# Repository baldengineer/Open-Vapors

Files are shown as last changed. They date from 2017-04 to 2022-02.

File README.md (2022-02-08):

# Open Vapors - Open Source Reflow Oven Controller

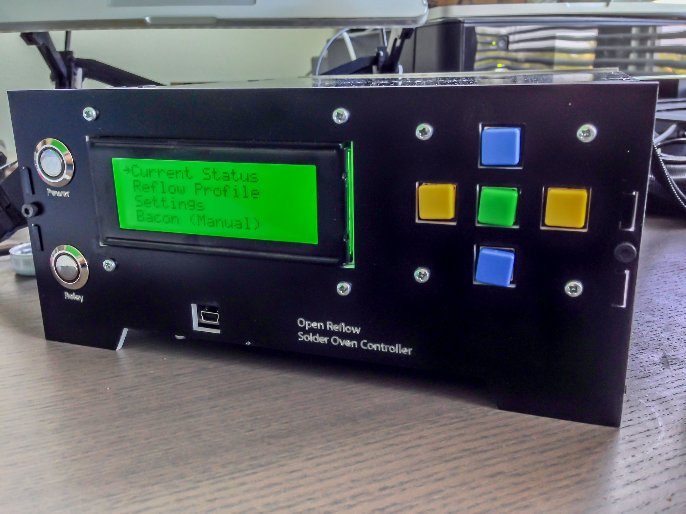
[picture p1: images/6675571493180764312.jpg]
bald engineer's open vapors reflow controller box


Additional Information on [baldengineer.com]( https://www.baldengineer.com/?s=open+vapors).

Key hardware pieces you'll need:
+ Toaster Oven with "Always On"
+ Custom controller board (or maybe an Arduino)
+ SSR (Recommend Crydom D2425)
+ 4-Line RGB LCD Display
+ 5 Button Keypad
+ 1 Push Button
+ Piezo Buzzer 

## /code
Contains all of the code for the menu display and reflow controller.

## /KiCad
The revision 2 board is a significant redesign from the first board. It integrates the shift register for the LCD and implements voltage rails to massively reduce internal wiring. Headers were also position to logical places on the PCB.

Buzzer is optional, but now implemented. USB connection through a 0.1" (2.54mm) header to a USB-port breakout. It is only intended for serial operation.

Recommend using ISP for programming. 

Also added port for AT-09 BLE module. (Not yet implemented)

## /enclosure
Laser cut enclosure. The top, bottom, and sides used 3mm black acrylic. The front and back panels are Black on White acrylic.

Originally designed in Autocad Inventor, student edition. Then exported to Adobe Illustrator (CS6 I think) files.

The bottom needs to be redesigned to get more support. ~~The SSR warps it over time.~~ After almost 5 years, it hasn't sagged anymore. I would still recommend a support around the SSR though.

## /original electronics - EAGLE
Rev 1 was created using an EAGLE. It worked okay, but relied on a "LCD Backpack" and was not an optimized design. (LEDs in the wrong place.) 

That said, it worked great for years.

The original keypad is in use still. Even though the debounce caps were totally wrong.

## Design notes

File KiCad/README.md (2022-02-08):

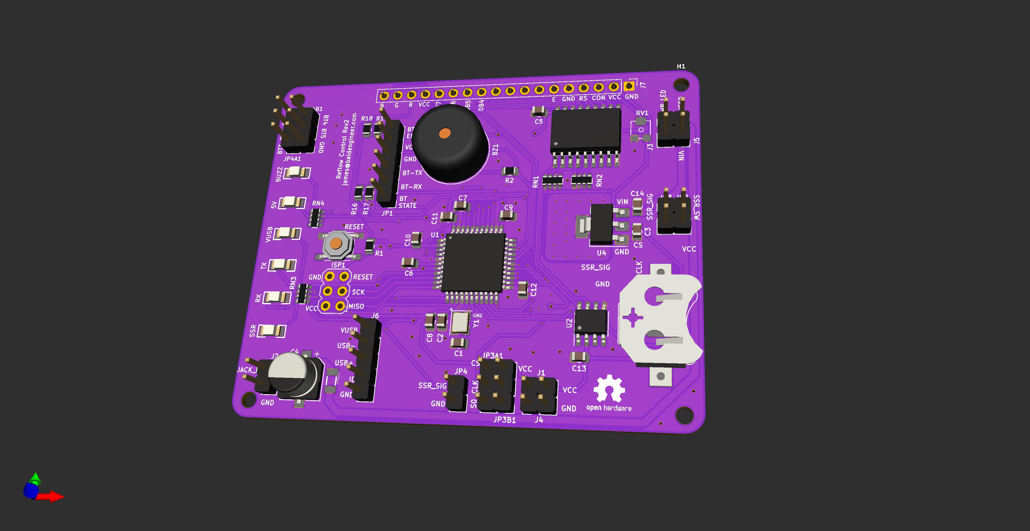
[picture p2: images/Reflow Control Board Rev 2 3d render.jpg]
board render


## KiCad Files
The first design used EAGLE 6. I converted the EAGLE files into KiCad 5. This reduced the time to re-capture the schematic but it also caused a mess with the libraries and silk screens.

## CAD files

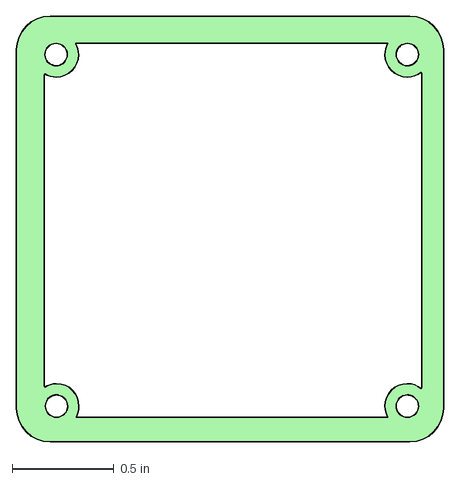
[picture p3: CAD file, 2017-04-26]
enclosure/spaces-3d-printed/Keypad Board/keypad_spacer.dxf
2.10 x 2.10 in

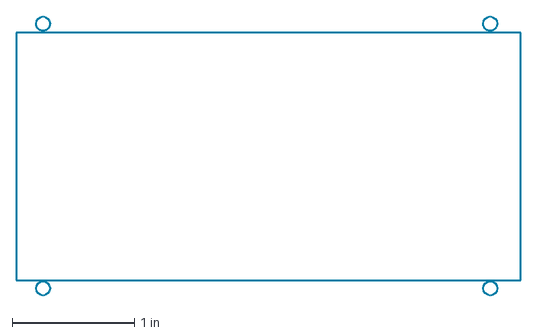
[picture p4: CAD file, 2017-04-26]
enclosure/spaces-3d-printed/lcd/lcd spacer for dxf.dxf
4.14 x 2.29 in

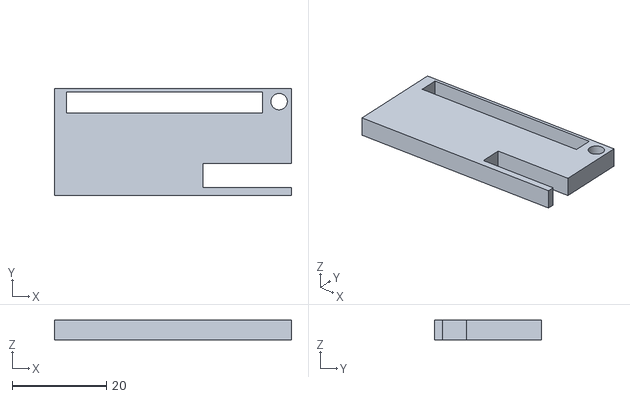
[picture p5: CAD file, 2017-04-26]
enclosure/spaces-3d-printed/spi backpack/spi backpack v1.stl
50.4 x 22.7 x 4.25

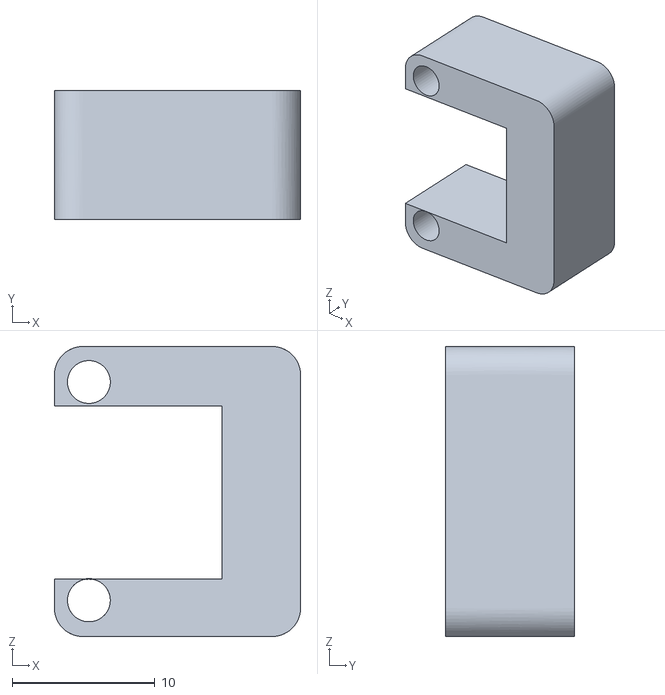
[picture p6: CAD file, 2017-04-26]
enclosure/spaces-3d-printed/thermo-board/thermo-v1.stl
17.2 x 9.00 x 20.3

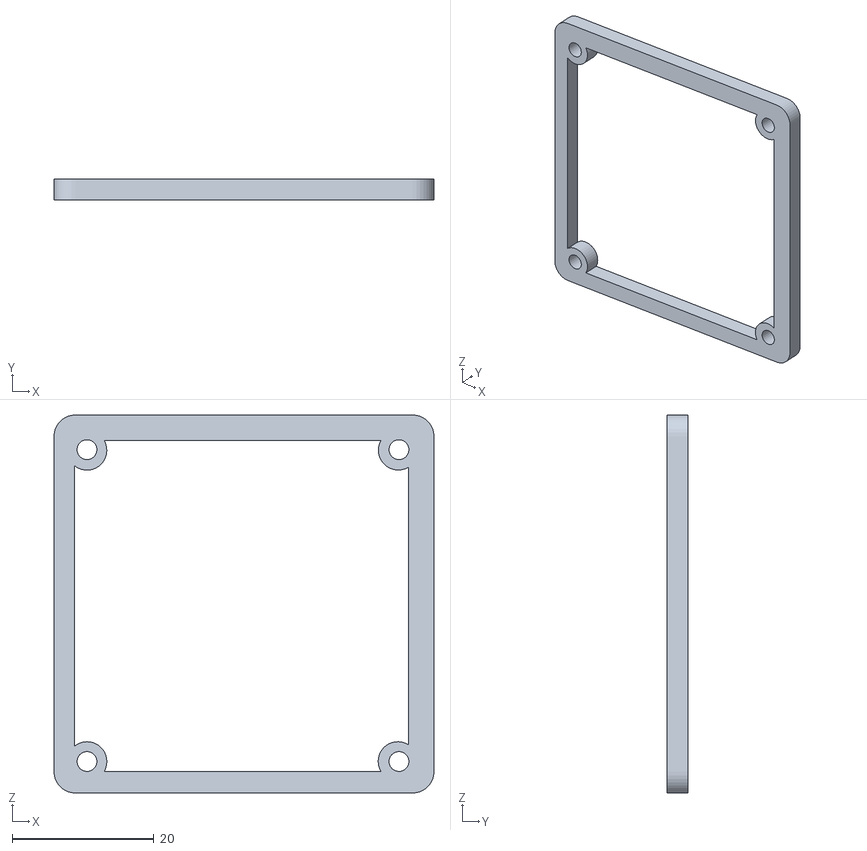
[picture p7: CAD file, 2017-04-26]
enclosure/spaces-3d-printed/Keypad Board/keyboard_space_cad.stl
53.6 x 3.00 x 53.3

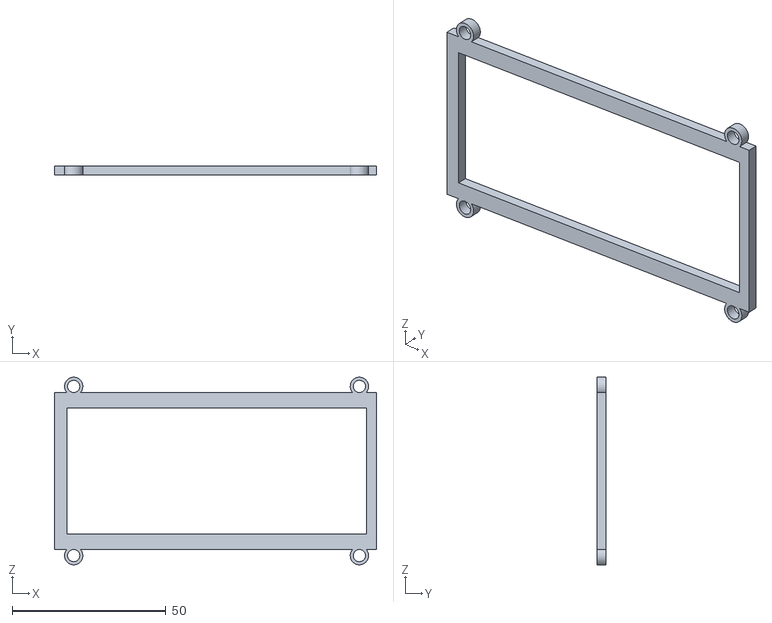
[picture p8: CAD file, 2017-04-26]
enclosure/spaces-3d-printed/lcd/lcd-v1.stl
104.9 x 3.00 x 61.1

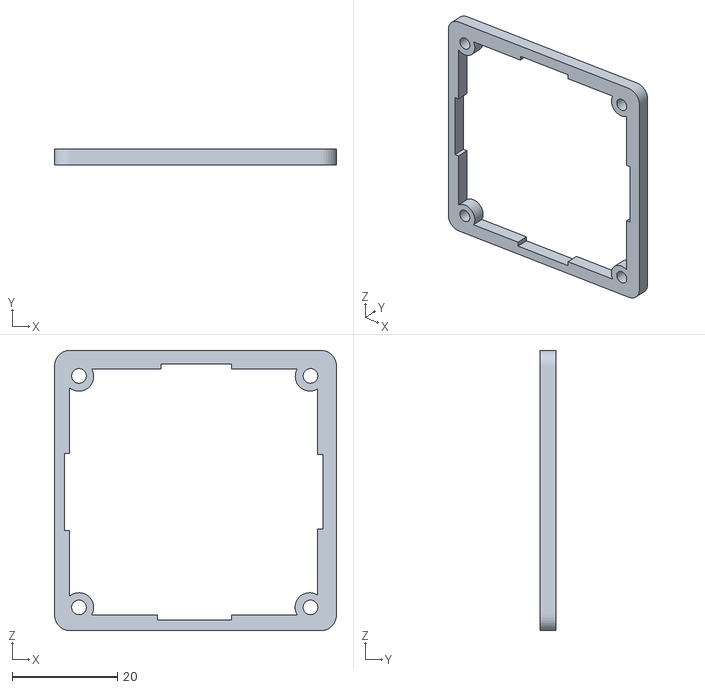
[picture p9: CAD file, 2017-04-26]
enclosure/spaces-3d-printed/Keypad Board/keyboard_space_cad2.stl
53.6 x 3.00 x 53.3

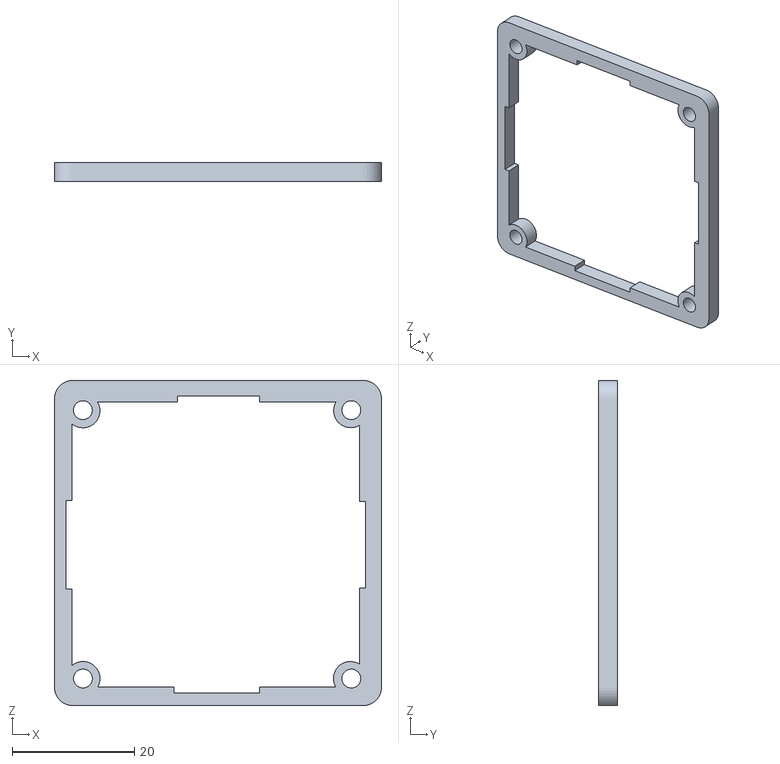
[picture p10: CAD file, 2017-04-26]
enclosure/spaces-3d-printed/Keypad Board/keyboard_space_cad3.stl
53.6 x 3.10 x 53.3

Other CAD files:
enclosure/box-autocad-inventor/Bottom Panel.ipt
enclosure/box-autocad-inventor/Box Back.ipt
enclosure/box-autocad-inventor/Box Bottom.ipt
enclosure/box-autocad-inventor/Box Front.ipt
enclosure/box-autocad-inventor/Box Side Panel.ipt
enclosure/box-autocad-inventor/Box Top.ipt
enclosure/box-autocad-inventor/Front Panel.ipt
enclosure/box-autocad-inventor/Reflow Oven Assembly.iam
enclosure/box-autocad-inventor/open reflow box.ipt
enclosure/spaces-3d-printed/Controller Board/cntrl-space-partA.ipt
enclosure/spaces-3d-printed/Keypad Board/keyboard_space_cad.ipt
enclosure/spaces-3d-printed/lcd/lcd-spacer-model.ipt
enclosure/spaces-3d-printed/spi backpack/spi backpack model.ipt
enclosure/spaces-3d-printed/thermo-board/thermo-model.ipt

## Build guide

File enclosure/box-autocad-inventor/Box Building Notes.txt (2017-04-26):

NEMA 5 model from GrabCad:  http://grabcad.com/library/industrial-grade-nema-5-15-duplex-receptacle

Panel Mount OUtlet:  http://www.mouser.com/catalog/specsheets/710w0003.pdf
http://www.mouser.com/ProductDetail/Qualtek/710W-00-03/?qs=sGAEpiMZZMv1TUPJeFpwbm7YVXuSB9VCPmF%252bPdpxbIk%3d

Panel Mount Inlet:  http://www.mouser.com/ds/1/337/744w0004-10363.pdf
http://www.mouser.com/ProductDetail/Qualtek/744W-00-04/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

Understanding engineering drawings: http://www.wisc-online.com/Objects/ViewObject.aspx?ID=ENG18704

Fuse Holder:  http://www1.cooperbussmann.com/pdf/6a0cf653-3423-48a4-b0d8-5b3b433e4858.pdf
http://www.mouser.com/Search/ProductDetail.aspx?qs=jGANiKWBgci5Io4vQID5Tg%3d%3d

Sharp Triac / SSR S216S02  http://sharp-world.com/products/device/lineup/data/pdf/datasheet/s116s02_e.pdf
beta layout reflow controller 120v

Dc Panel Mount:
http://www.mouser.com/catalog/specsheets/KC-301074.pdf
http://www.mouser.com/ProductDetail/Kobiconn/163-R123B-E/?qs=sGAEpiMZZMu2f9RNbWupYr29NQTi4RUSfGRFGZxAbjk%3d

Terminal Blocks
http://www.mouser.com/Search/ProductDetail.aspx?qs=nJOu%252bf4e%252bhtchGRXi4U3dQ%3d%3d

Check out skyrocket:  http://skyrockettheband.com/video_index.html

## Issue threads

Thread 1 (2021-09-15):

rev2 pcb for controller has battery mistake

baldengineer, 2021-09-15:
The RTC's battery connector footprint does not connect to GND. There is a mistake in the KiCad schematic that did not connect the nets.

It is necessary to scrape the solder mask and bodge a connection to the nearby GND.

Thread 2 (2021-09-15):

Power LED connector is not connected

baldengineer, 2021-09-15:
On the pin headers for the front panel buttons, there is a pin for "power LED." the Pin on the  2x1 (or 2x2, depending on how you look at it) isn't connected to anything.

Need to connect front panel's switches power LED to a 5V node elsewhere.

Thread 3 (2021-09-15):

PID is wonky

baldengineer, 2021-09-15:
In reviewing the latest reflow state machine and PID code, it is clear the intern took the "hardcode the profile" shortcut.

While changing the profile is possible, the state machine has several shortcuts that should have been figured out with proper tuning.

Will schedule a sit-down with the intern.

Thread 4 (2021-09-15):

Add a fan

baldengineer, 2021-09-15:
The PID would be significantly more effective if fan control was possible.

Is there a way to add a fan to the oven that won't melt?

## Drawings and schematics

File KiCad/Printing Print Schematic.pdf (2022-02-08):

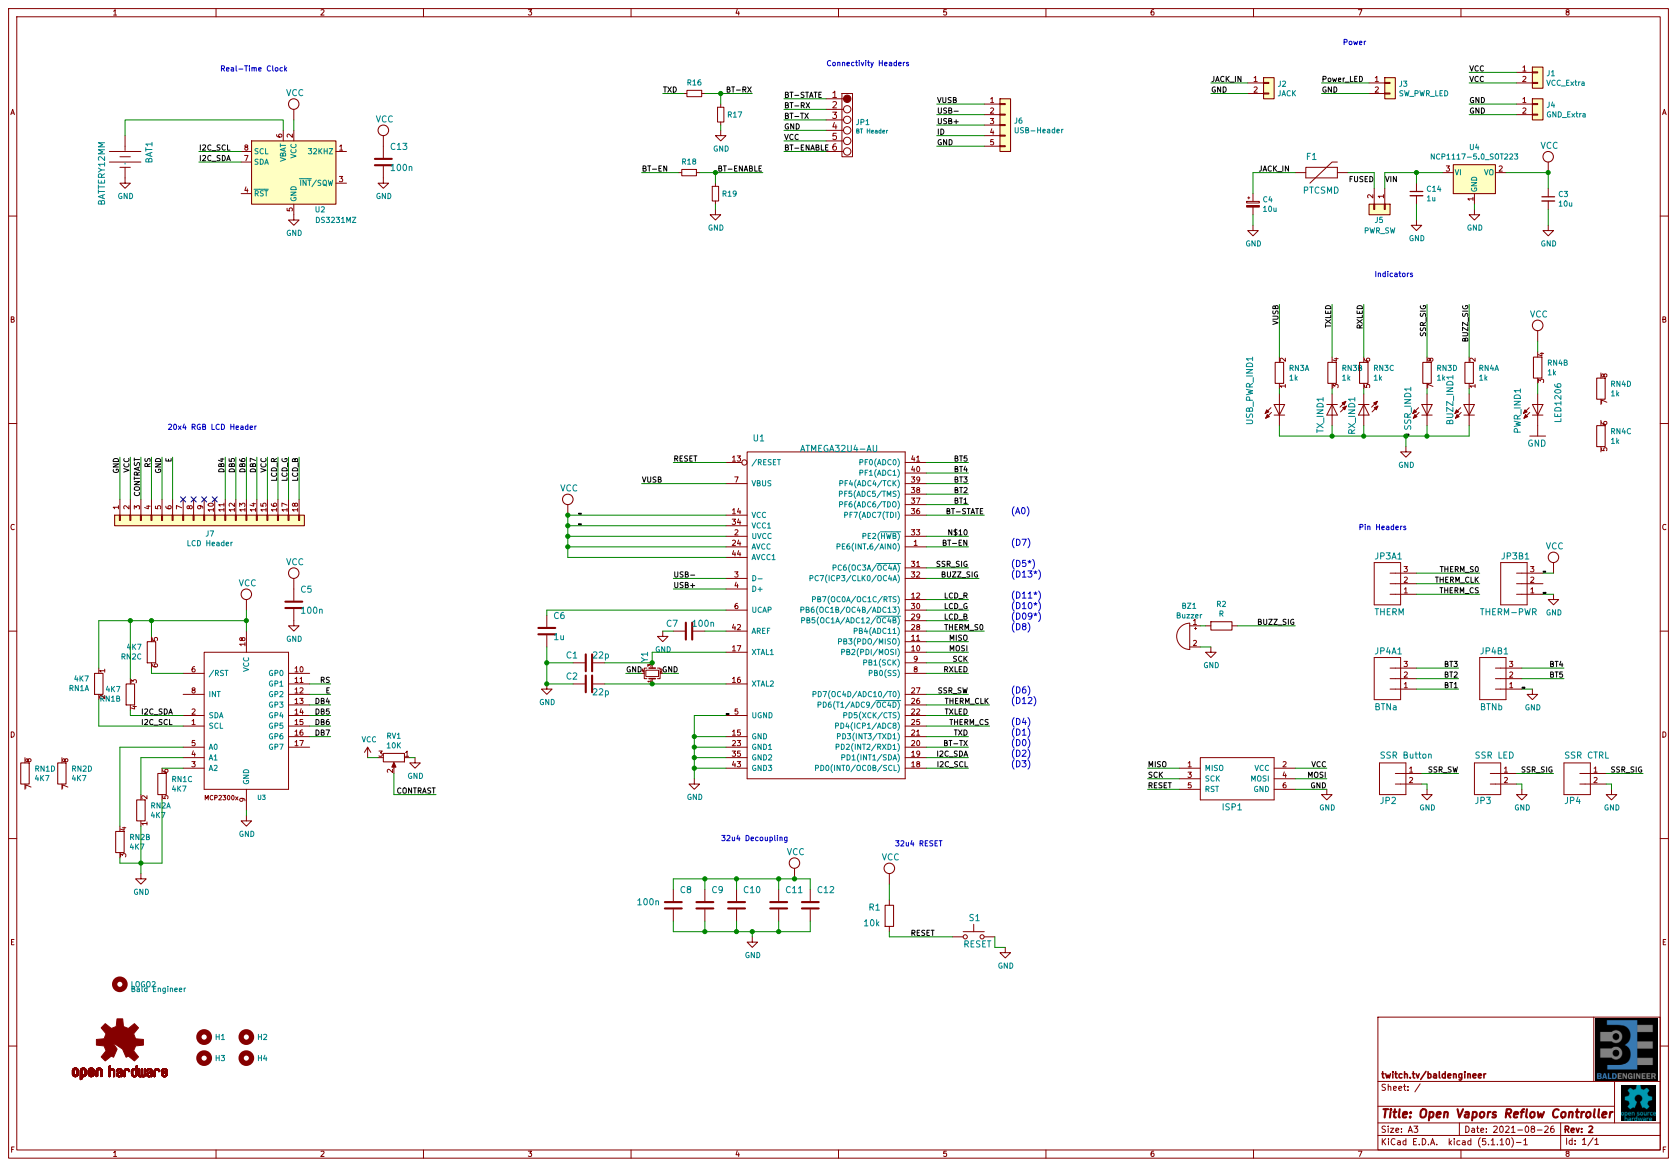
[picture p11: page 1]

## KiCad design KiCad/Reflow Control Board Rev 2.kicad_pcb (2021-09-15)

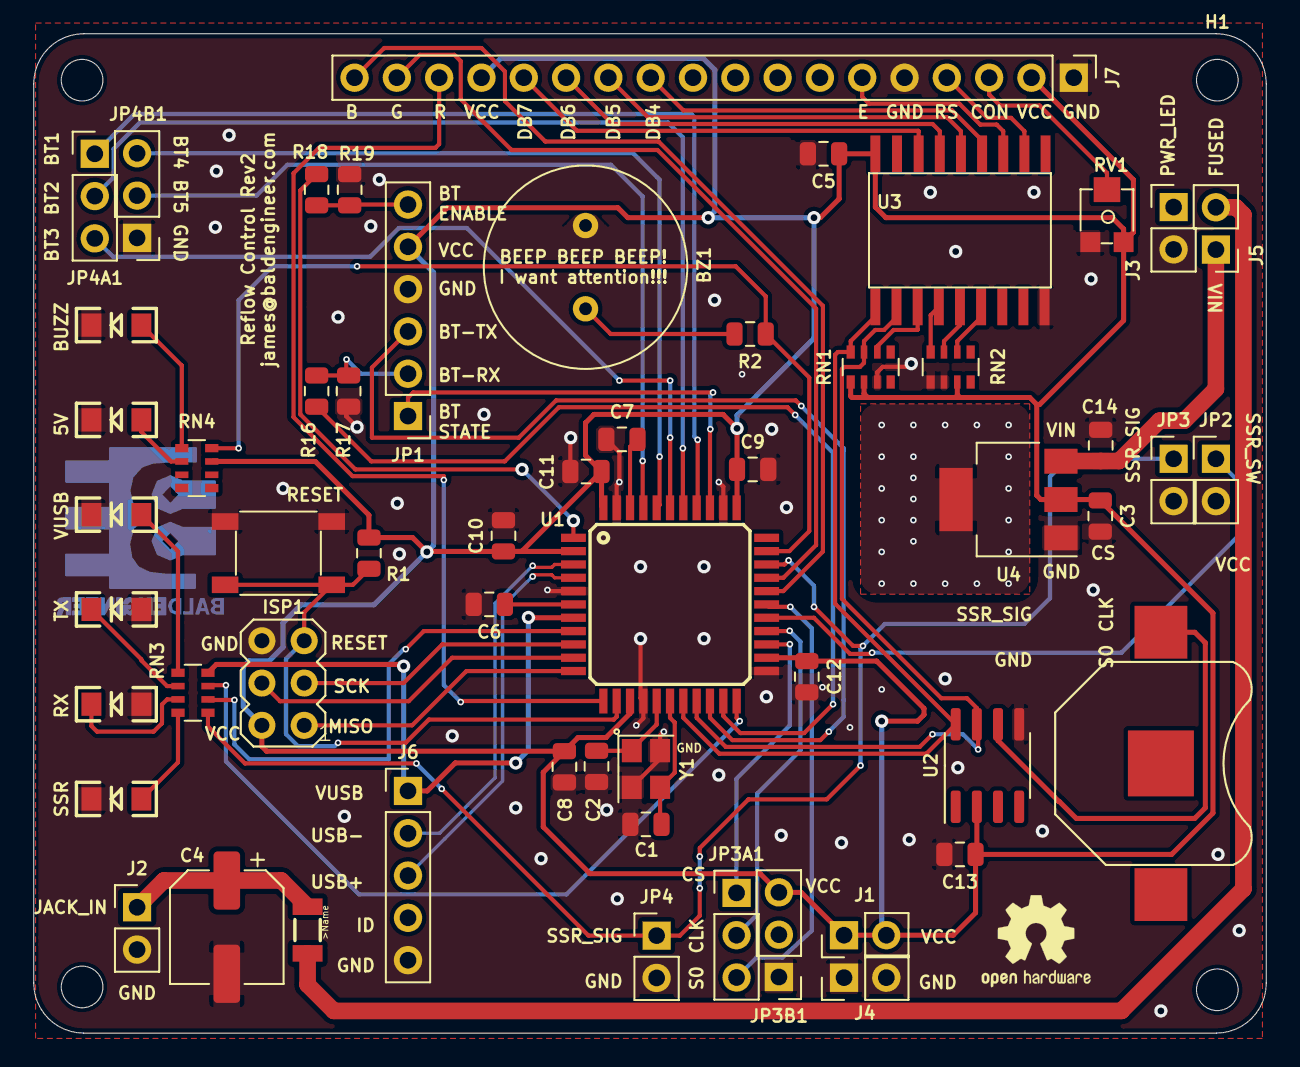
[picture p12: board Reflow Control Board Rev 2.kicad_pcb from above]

Board: 2 copper layers, 74.0 x 60.0 mm, 62 parts (0 on the bottom side), 59 nets.

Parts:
BAT1: BATTERY12MM; BATTCON_12MM
BUZZ_IND1: LED1206; LED-1206
BZ1: Buzzer; 12mm_Piezo_Buzzer
C1, C2: 22p; C_0805_2012Metric
C3: 10u; C_0805_2012Metric
C4: 10u; CP_Elec_6.3x5.9
C5, C7, C8, C9, C10, C11, C12, C13: 100n; C_0805_2012Metric
C6, C14: 1u; C_0805_2012Metric
F1: PTCSMD; PTC-1206
H1, H2, H3, H4: MountingHole; MountingHole_2.5mm
ISP1: AVRISP-6; AVRISP
J1: VCC_Extra; PinHeader_1x02_P2.54mm_Vertical
J2: JACK; PinHeader_1x02_P2.54mm_Vertical
J3: SW_PWR_LED; PinHeader_1x02_P2.54mm_Vertical
J4: GND_Extra; PinHeader_1x02_P2.54mm_Vertical
J5: PWR_SW; PinHeader_1x02_P2.54mm_Vertical
J6: USB-Header; PinHeader_1x05_P2.54mm_Vertical
J7: LCD Header; PinHeader_1x18_P2.54mm_Vertical
JP1: BT Header; PinHeader_1x06_P2.54mm_Vertical
JP2: SSR Button; PinHeader_1x02_P2.54mm_Vertical
JP3: SSR LED; PinHeader_1x02_P2.54mm_Vertical
JP3A1: THERM; PinHeader_1x03_P2.54mm_Vertical
JP3B1: THERM-PWR; PinHeader_1x03_P2.54mm_Vertical
JP4: SSR CTRL; PinHeader_1x02_P2.54mm_Vertical
JP4A1: BTNa; PinHeader_1x03_P2.54mm_Vertical
JP4B1: BTNb; PinHeader_1x03_P2.54mm_Vertical
LOGO1: OSHW-LOGOM; OSHW-Logo2_7.3x6mm_SilkScreen
PWR_IND1: LED1206; LED-1206
R1: 10k; R_0805_2012Metric
R2: R; R_0805_2012Metric
R16, R17, R18, R19: R_Small; R_0805_2012Metric
RN1, RN2: 4K7; R_Array_Convex_4x0603
RN3, RN4: 1k; R_Array_Convex_4x0603
RV1: 10K; EVM3Y
RX_IND1: LED1206; LED-1206
S1: RESET; SW_Push_CK_PTS525_SM15
SSR_IND1: LED1206; LED-1206
TX_IND1: LED1206; LED-1206
U1: ATMEGA32U4-AU; TQFP44
U2: DS3231MZ; SOIC-8_3.9x4.9mm_P1.27mm
U3: MCP2300X_SO; SO18W
U4: NCP1117-5.0_SOT223; SOT-223-3_TabPin2
USB_PWR_IND1: LED1206; LED-1206
Y1: CRYSTALHC49US; Crystal_SMD_Abracon_ABM8G-4Pin_3.2x2.5mm
svg2mod: G***; BE20

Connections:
/BT1: JP4A1.1, U1.37
/BT2: JP4A1.2, U1.38
/BT3: JP4A1.3, U1.39
/BT4: JP4B1.3, U1.40
/BT5: JP4B1.2, U1.41
/BT-EN: R18.2, U1.1
/BT-ENABLE: JP1.6, R18.1, R19.1
/BT-RX: JP1.2, R16.1, R17.1
/BT-STATE: JP1.1, U1.36
/BT-TX: JP1.3, U1.20
/BUZZ_SIG: R2.1, RN4.2, U1.32
/CONTRAST: J7.3, RV1.2
/DB4: J7.11, U3.13
/DB5: J7.12, U3.14
/DB6: J7.13, U3.15
/DB7: J7.14, U3.16
/E: J7.6, U3.12
/FUSED: F1.2, J5.2
/I2C_SCL: RN1.2, U1.18, U2.8, U3.1
/I2C_SDA: RN1.4, U1.19, U2.7, U3.2
/JACK_IN: C4.1, F1.1, J2.1
/LCD_B: J7.18, U1.29
/LCD_G: J7.17, U1.30
/LCD_R: J7.16, U1.12
/MISO: ISP1.1, U1.11
/MOSI: ISP1.4, U1.10
/RESET: ISP1.5, R1.2, S1.1, U1.13
/RS: J7.4, U3.11
/RXLED: RN3.6, U1.8
/SCK: ISP1.3, U1.9
/SSR_SIG: JP3.1, JP4.1, RN3.8, U1.31
/SSR_SW: JP2.1, U1.27
/THERM_CLK: JP3A1.2, U1.26
/THERM_CS: JP3A1.1, U1.25
/THERM_S0: JP3A1.3, U1.28
/TXD: R16.2, U1.21
/TXLED: RN3.4, U1.22
/USB+: J6.3, U1.4
/USB-: J6.2, U1.3
/VIN: C14.1, J5.1, U4.3
/VUSB: J6.1, RN3.2, U1.7
GND: BUZZ_IND1.C, BZ1.2, C1.1, C2.1, C3.2, C4.2, C5.2, C6.2, C7.1, C8.2, C9.2, C10.2, C11.2, C12.2, C13.2, C14.2, ISP1.6, J2.2, J3.2, J4.1, J4.2, J6.5, J7.1, J7.5, JP1.4, JP2.2, JP3.2, JP3B1.1, JP4.2, JP4B1.1, PWR_IND1.C, R17.2, R19.2, RN1.5, RN2.1, RN2.3, RV1.1, RX_IND1.A, S1.2, SSR_IND1.C, TX_IND1.A, U1.5, U1.15, U1.23, U1.35, U1.43, U2.5, U3.9, U4.1, USB_PWR_IND1.C, Y1.2, Y1.4
unnamed: BAT1.PWR@2, U2.6
unnamed: BUZZ_IND1.A, RN4.1
unnamed: BZ1.1, R2.2
unnamed: C1.2, U1.17, Y1.3
unnamed: C2.2, U1.16, Y1.1
unnamed: C6.1, U1.6
unnamed: C7.2, U1.42
unnamed: PWR_IND1.A, RN4.3
unnamed: RN1.6, U3.3
unnamed: RN2.2, U3.4
unnamed: RN2.4, U3.5
unnamed: RN2.6, U3.6
unnamed: RN3.1, USB_PWR_IND1.A
unnamed: RN3.3, TX_IND1.C
unnamed: RN3.5, RX_IND1.C
unnamed: RN3.7, SSR_IND1.A
VCC: C3.1, C5.1, C8.1, C9.1, C10.1, C11.1, C12.1, C13.1, ISP1.2, J1.1, J1.2, J7.2, J7.15, JP1.5, JP3B1.3, R1.1, RN1.1, RN1.3, RN2.5, RN4.4, RV1.3, U1.2, U1.14, U1.24, U1.34, U1.44, U2.2, U3.18, U4.2

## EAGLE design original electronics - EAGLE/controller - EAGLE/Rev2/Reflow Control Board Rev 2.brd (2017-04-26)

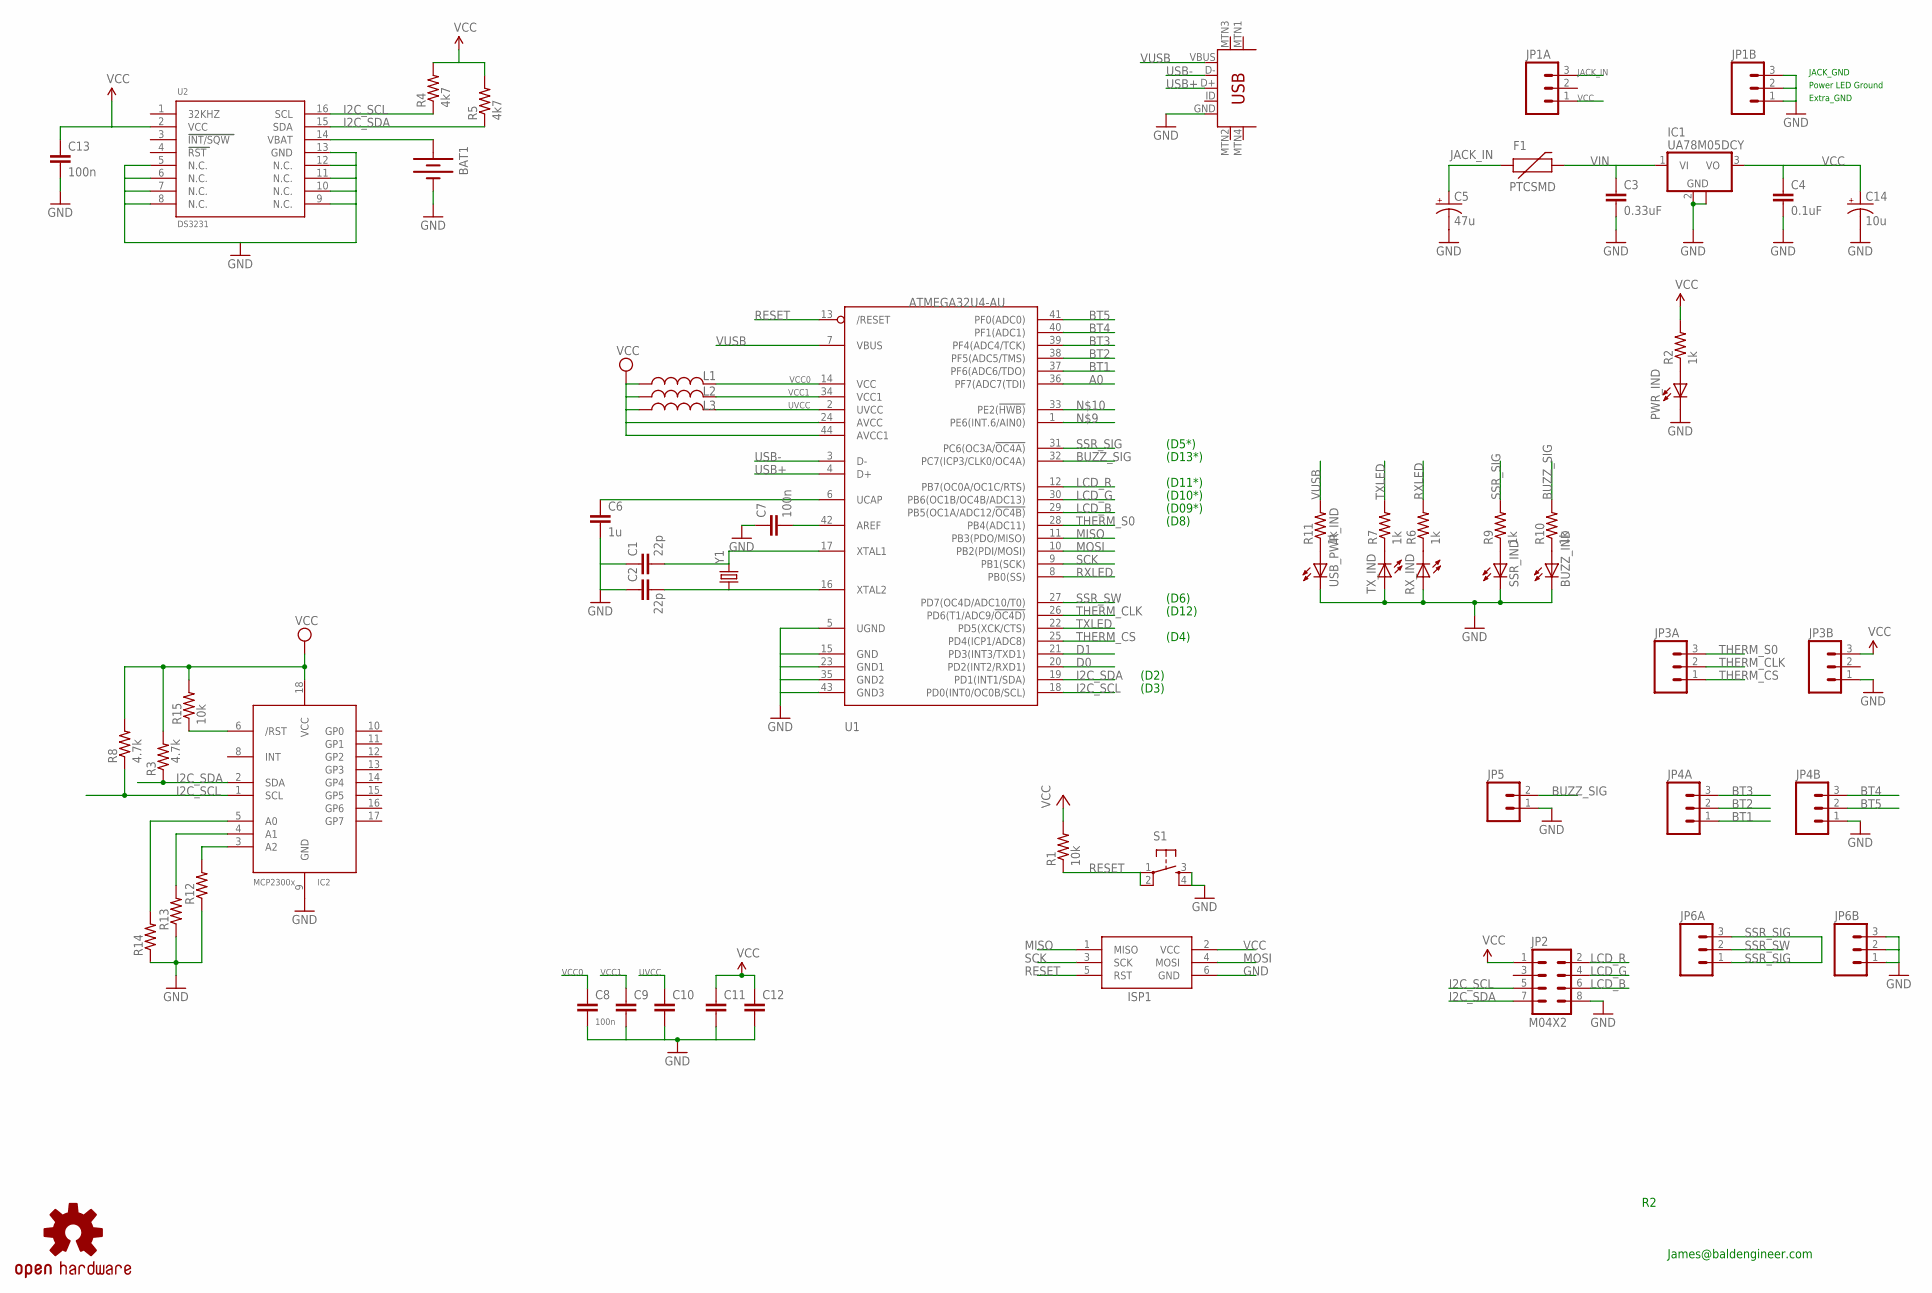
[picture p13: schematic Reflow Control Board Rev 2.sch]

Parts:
BAT1: BATTERY12MM; BATTCON_12MM
BUZZ_IND: LED1206; LED-1206
C1, C2: 22p; 1206
C3: 0.33uF; 1206
C4: 0.1uF; 1206
C5: 47u; D/7343-31R
C6: 1u; 1206
C7, C8, C9, C10, C11, C12, C13: 100n; 1206
C14: 10u; D/7343-31R
F1: PTCSMD; PTC-1206
IC1: UA78M05DCY; SOT223
IC2: MCP2300X/SO; SO18W
ISP1: AVRISP-6; AVRISP
JP1A, JP1B, JP3A, JP3B, JP4A, JP4B, JP6A, JP6B: M03LOCK; 1X03_LOCK
JP2: M04X2; 2X4
JP5: M02LOCK; 1X02_LOCK
L1, L2, L3: INDUCTOR0805; 0805
PWR_IND: LED1206; LED-1206
R1, R15: 10k; 1206
R2, R6, R7, R9, R10, R11: 1k; 1206
R3, R8: 4.7k; 1206
R4, R5: 4k7; 1206
R12, R13, R14: RESISTOR1206; 1206
RX_IND: LED1206; LED-1206
S1: TAC_SWITCHSMD; TACTILE_SWITCH_SMD
SSR_IND: LED1206; LED-1206
TX_IND: LED1206; LED-1206
U1: ATMEGA32U4-AU; TQFP44
U2: DS3231; SO16L
U$3: USB-MINIB-5PIN; USB-MINIB
U$4: OSHW-LOGOS; OSHW-LOGO-S
USB_PWR_IND: LED1206; LED-1206
Y1: CRYSTALHC49US; HC49US

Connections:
A0: U1.36 (PF7(ADC7(TDI))
BT1: JP4A.1, U1.37 (PF6(ADC6/TDO))
BT2: JP4A.2, U1.38 (PF5(ADC5/TMS))
BT3: JP4A.3, U1.39 (PF4(ADC4/TCK))
BT4: JP4B.3, U1.40 (PF1(ADC1))
BT5: JP4B.2, U1.41 (PF0(ADC0))
BUZZ_SIG: JP5.2, R10.2, U1.32 (PC7(ICP3/CLK0/OC4A))
D0: U1.20 (PD2(INT2/RXD1))
D1: U1.21 (PD3(INT3/TXD1))
GND: BAT1.GND (-), BUZZ_IND.C, C1.1, C2.1, C3.2, C4.2, C5.-, C6.2, C7.1, C8.2, C9.2, C10.2, C11.2, C12.2, C13.2, C14.-, IC1.2 (GND), IC1.4 (GND), IC2.9 (GND), ISP1.6 (GND), JP1B.1, JP1B.2, JP1B.3, JP2.8, JP3B.1, JP4B.1, JP5.1, JP6B.1, JP6B.2, JP6B.3, PWR_IND.C, R12.1, R13.1, R14.1, RX_IND.A, S1.3, S1.4, SSR_IND.C, TX_IND.A, U1.5 (UGND), U1.15 (GND), U1.23 (GND1), U1.35 (GND2), U1.43 (GND3), U2.5 (N.C.), U2.6 (N.C.), U2.7 (N.C.), U2.8 (N.C.), U2.9 (N.C.), U2.10 (N.C.), U2.11 (N.C.), U2.12 (N.C.), U2.13 (GND), U$3.GND, USB_PWR_IND.C
I2C_SCL: IC2.1 (SCL), JP2.5, R4.1, R8.1, U1.18 (PD0(INT0/OC0B/SCL)), U2.16 (SCL)
I2C_SDA: IC2.2 (SDA), JP2.7, R3.1, R5.1, U1.19 (PD1(INT1/SDA)), U2.15 (SDA)
JACK_IN: C5.+, F1.1, JP1A.3
LCD_B: JP2.6, U1.29 (PB5(OC1A/ADC12/!OC4B))
LCD_G: JP2.4, U1.30 (PB6(OC1B/OC4B/ADC13))
LCD_R: JP2.2, U1.12 (PB7(OC0A/OC1C/RTS))
MISO: ISP1.1 (MISO), U1.11 (PB3(PDO/MISO))
MOSI: ISP1.4 (MOSI), U1.10 (PB2(PDI/MOSI))
unnamed: C1.2, U1.17 (XTAL1), Y1.2
unnamed: C2.2, U1.16 (XTAL2), Y1.1
unnamed: R7.1, TX_IND.C
unnamed: C6.1, U1.6 (UCAP)
unnamed: C7.2, U1.42 (AREF)
unnamed: PWR_IND.A, R2.1
unnamed: R6.1, RX_IND.C
unnamed: R9.1, SSR_IND.A
unnamed: BAT1.PWR@2 (+), U2.14 (VBAT)
unnamed: IC2.3 (A2), R12.2
unnamed: BUZZ_IND.A, R10.1
unnamed: R11.1, USB_PWR_IND.A
unnamed: IC2.4 (A1), R13.2
unnamed: IC2.5 (A0), R14.2
unnamed: IC2.6 (/RST), R15.1
RESET: ISP1.5 (RST), R1.1, S1.1, S1.2, U1.13 (/RESET)
RXLED: R6.2, U1.8 (PB0(SS))
SCK: ISP1.3 (SCK), U1.9 (PB1(SCK))
SSR_SIG: JP6A.1, JP6A.3, R9.2, U1.31 (PC6(OC3A/!OC4A))
SSR_SW: JP6A.2, U1.27 (PD7(OC4D/ADC10/T0))
THERM_CLK: JP3A.2, U1.26 (PD6(T1/ADC9/!OC4D))
THERM_CS: JP3A.1, U1.25 (PD4(ICP1/ADC8))
THERM_S0: JP3A.3, U1.28 (PB4(ADC11))
TXLED: R7.2, U1.22 (PD5(XCK/CTS))
USB+: U1.4 (D+), U$3.D+
USB-: U1.3 (D-), U$3.D-
UVCC: C10.1, L3.2, U1.2 (UVCC)
VCC: C4.1, C11.1, C12.1, C13.1, C14.+, IC1.3 (VO), IC2.18 (VCC), ISP1.2 (VCC), JP1A.1, JP2.1, JP3B.3, L1.1, L2.1, L3.1, R1.2, R2.2, R3.2, R4.2, R5.2, R8.2, R15.2, U1.24 (AVCC), U1.44 (AVCC1), U2.2 (VCC)
VCC0: C8.1, L1.2, U1.14 (VCC)
VCC1: C9.1, L2.2, U1.34 (VCC1)
VIN: C3.1, F1.2, IC1.1 (VI)
VUSB: R11.2, U1.7 (VBUS), U$3.VBUS

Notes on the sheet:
Power LED Ground
JACK_GND
Extra_GND
(D2)
(D3)
(D4)
(D12)
(D8)
(D13*)
(D5*)
(D09*)
(D10*)
(D11*)
(D6)
James@baldengineer.com

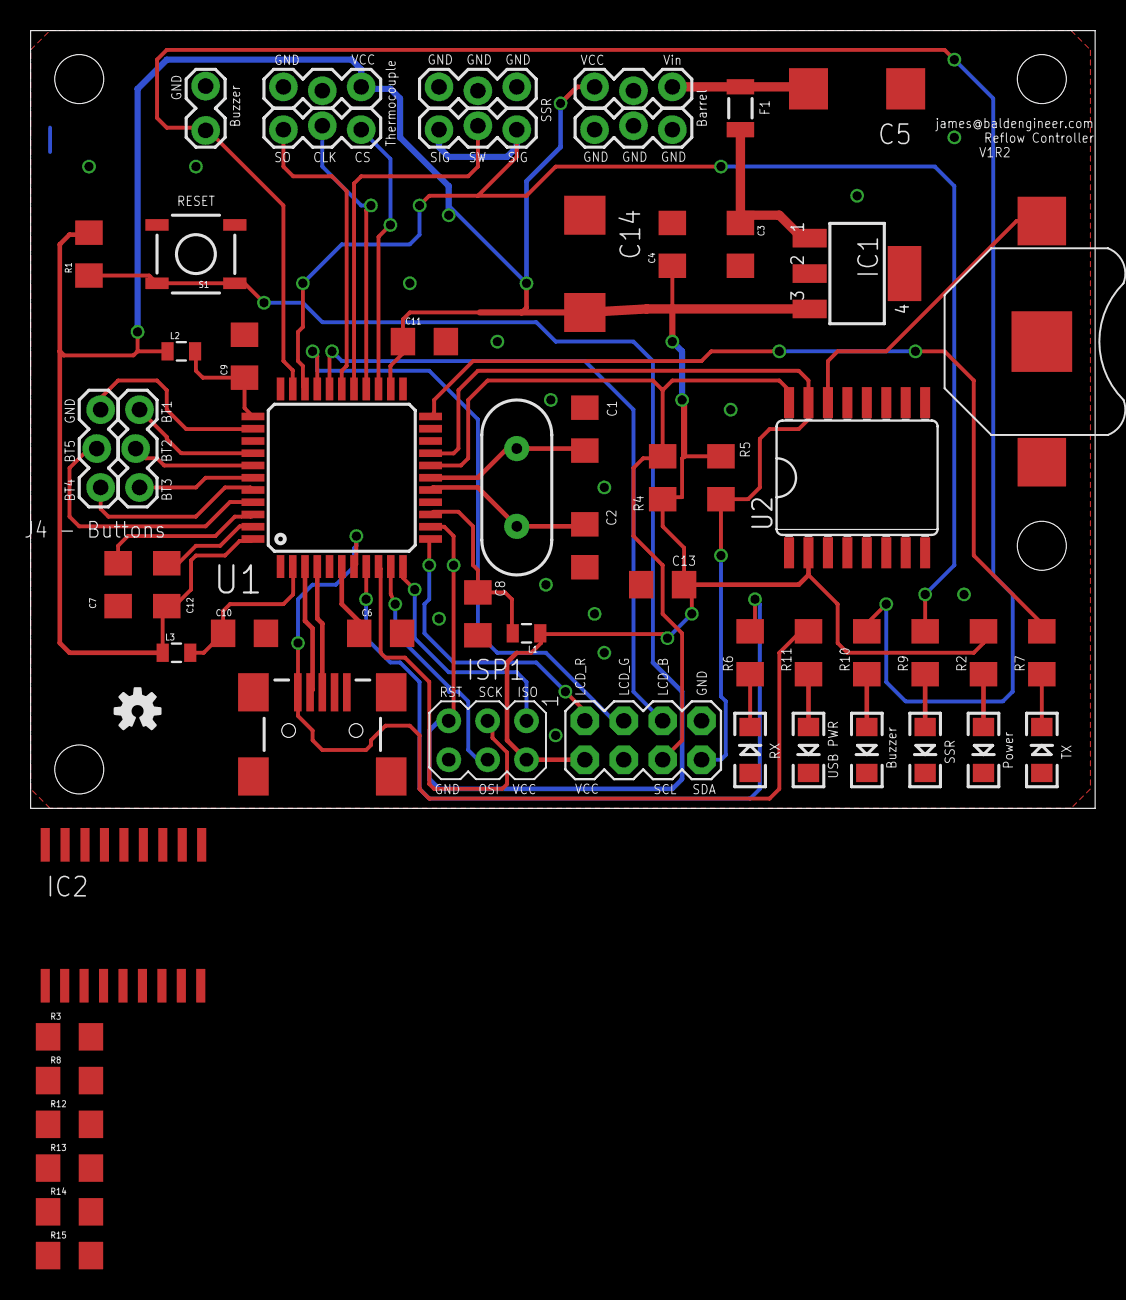
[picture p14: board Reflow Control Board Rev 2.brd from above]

Board: 2 copper layers, 69.5 x 50.8 mm, 59 parts (0 on the bottom side), 47 nets.

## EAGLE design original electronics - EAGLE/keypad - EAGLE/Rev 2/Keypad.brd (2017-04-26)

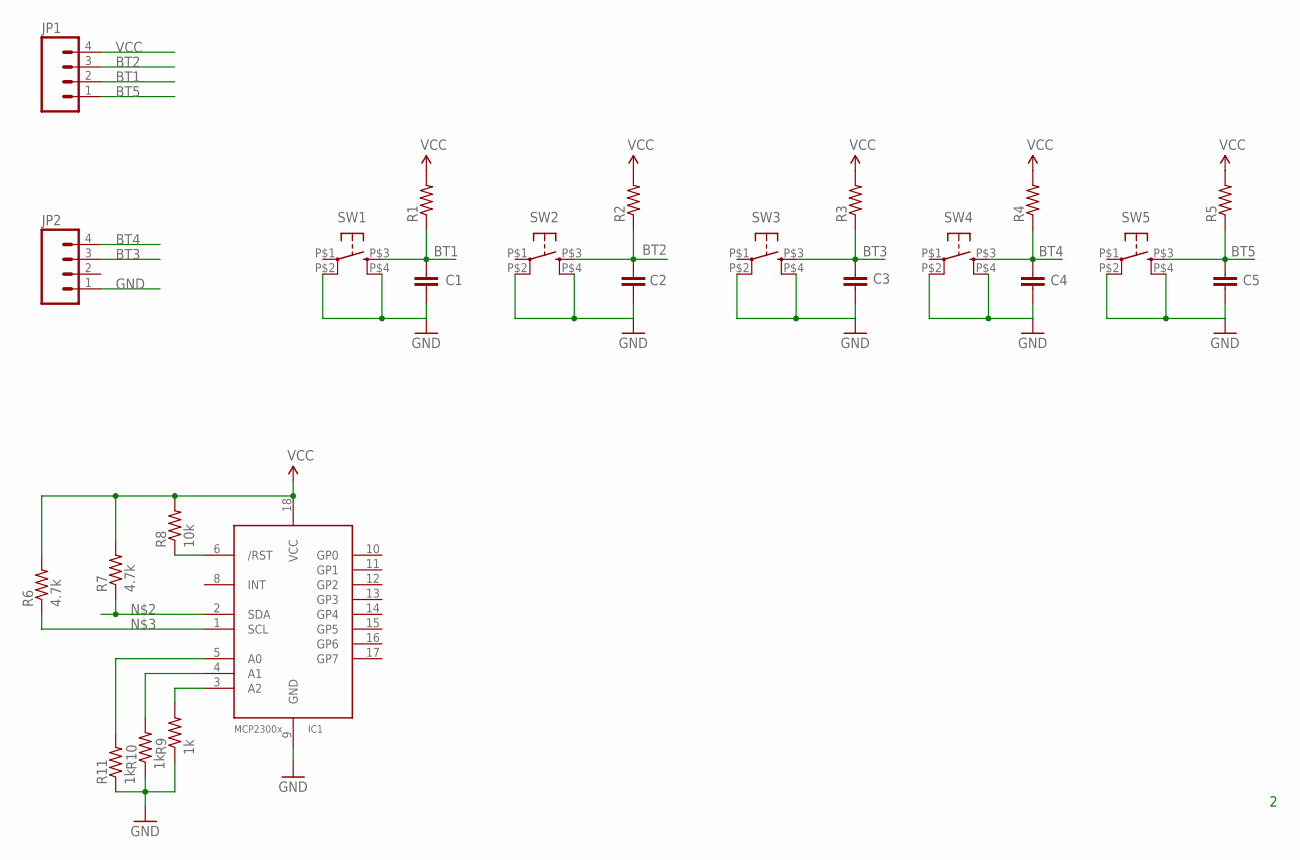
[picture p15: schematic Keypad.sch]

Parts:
C1, C2, C3, C4, C5: CAP1206; 1206
IC1: MCP2300X/SO; SO18W
JP1, JP2: M04LOCK; 1X04_LOCK
R1, R2, R3, R4, R5: RESISTOR1206; 1206
R6, R7: 4.7k; 1206
R8: 10k; 1206
R9, R10, R11: 1k; 1206
SW1, SW2, SW3, SW4, SW5: TAC_PTH_12MM; TACTILE-PTH-12MM

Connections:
BT1: C1.1, JP1.2, R1.1, SW1.P$3 (3)
BT2: C2.1, JP1.3, R2.1, SW2.P$3 (3)
BT3: C3.1, JP2.3, R3.1, SW3.P$3 (3)
BT4: C4.1, JP2.4, R4.1, SW4.P$3 (3)
BT5: C5.1, JP1.1, R5.1, SW5.P$3 (3)
GND: C1.2, C2.2, C3.2, C4.2, C5.2, IC1.9 (GND), JP2.1, R9.1, R10.1, R11.1, SW1.P$2 (2), SW1.P$4 (4), SW2.P$2 (2), SW2.P$4 (4), SW3.P$2 (2), SW3.P$4 (4), SW4.P$2 (2), SW4.P$4 (4), SW5.P$2 (2), SW5.P$4 (4)
unnamed: IC1.2 (SDA), R7.1
unnamed: IC1.1 (SCL), R6.1
unnamed: IC1.6 (/RST), R8.1
unnamed: IC1.3 (A2), R9.2
unnamed: IC1.4 (A1), R10.2
unnamed: IC1.5 (A0), R11.2
VCC: IC1.18 (VCC), JP1.4, R1.2, R2.2, R3.2, R4.2, R5.2, R6.2, R7.2, R8.2

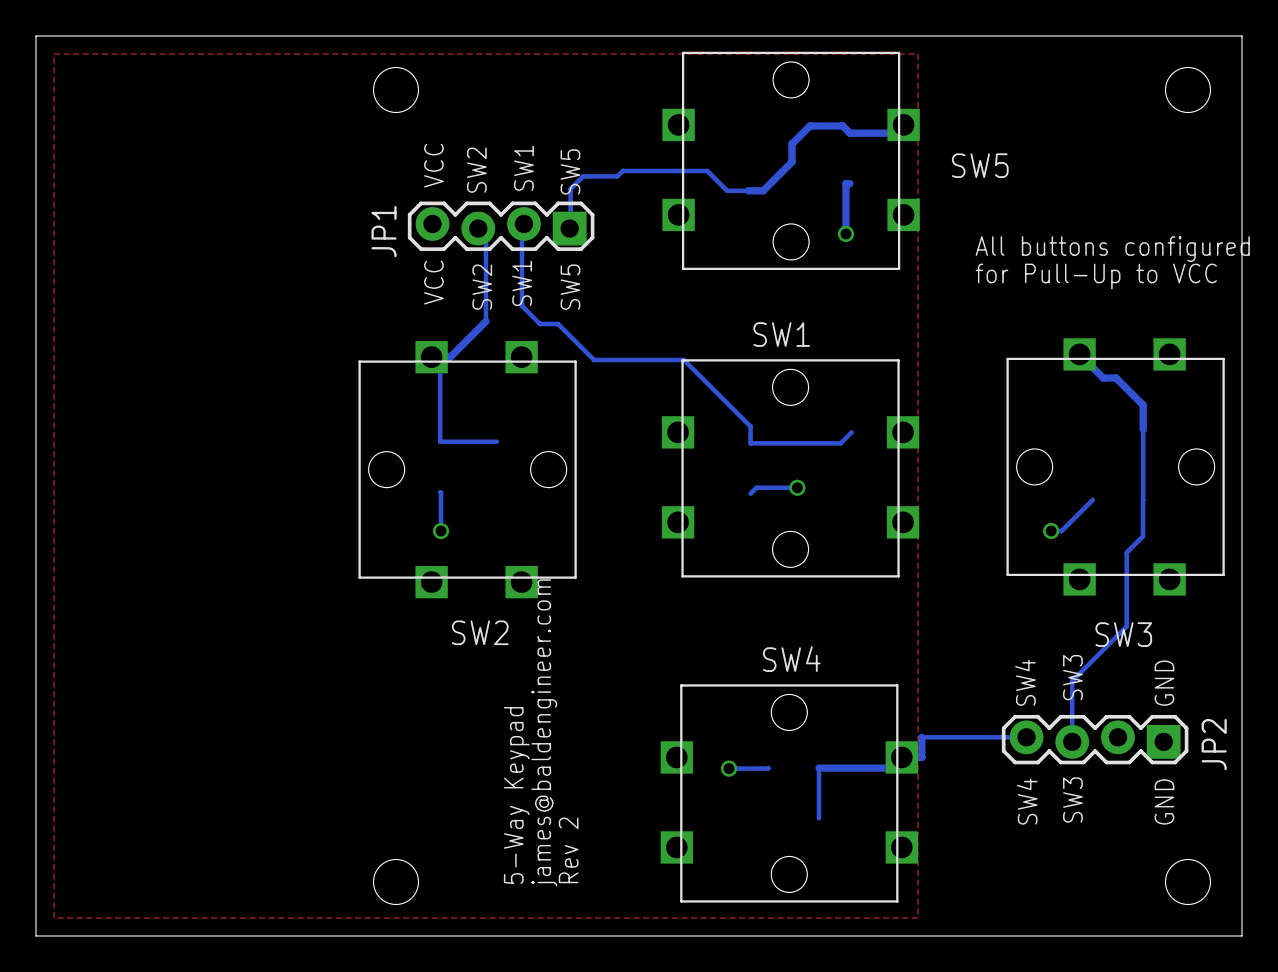
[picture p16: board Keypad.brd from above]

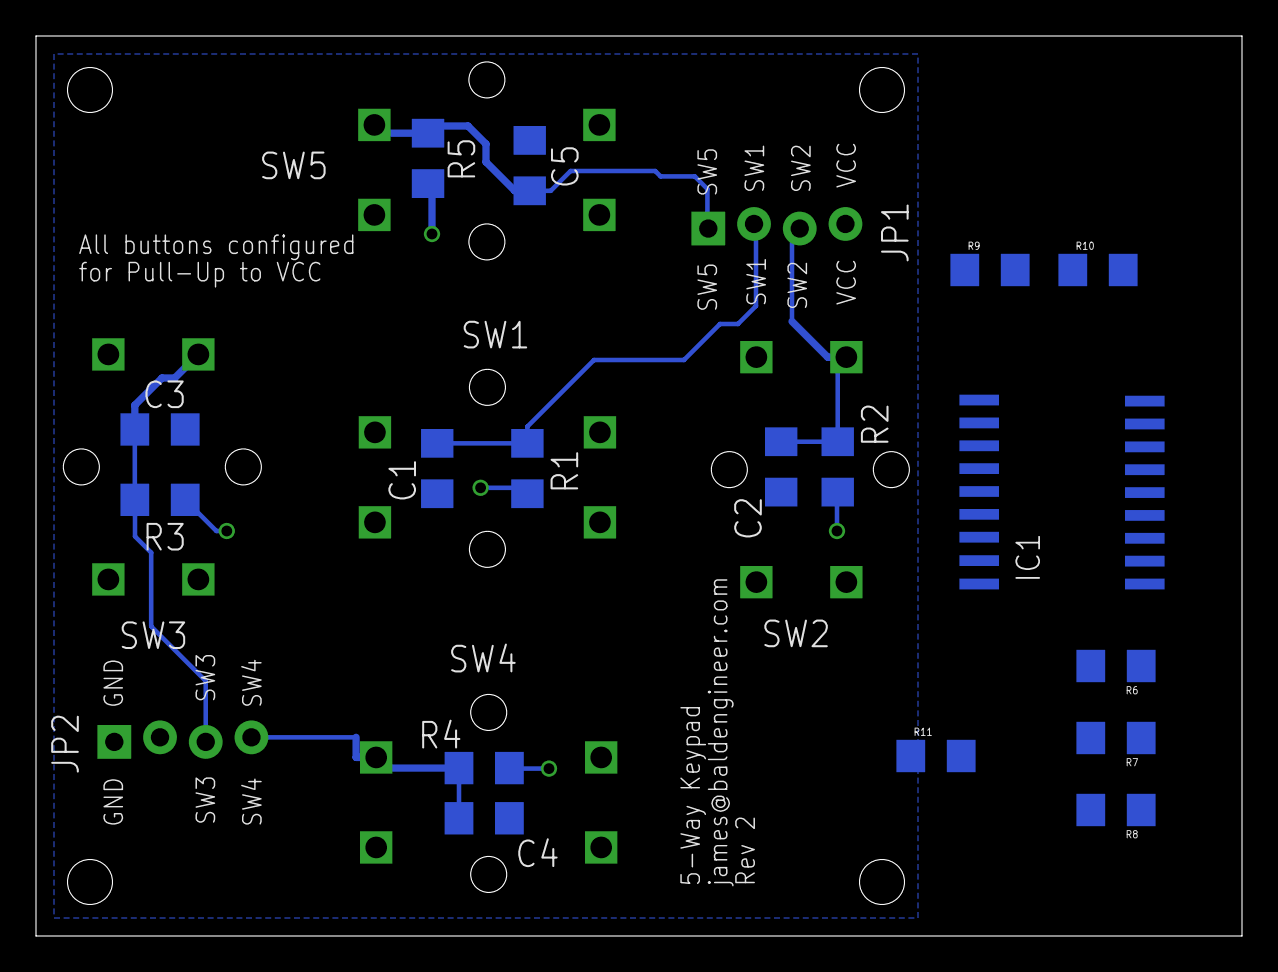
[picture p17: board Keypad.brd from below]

Board: 2 copper layers, 67.0 x 50.0 mm, 24 parts (17 on the bottom side), 13 nets.

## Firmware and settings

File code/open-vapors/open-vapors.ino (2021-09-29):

#include "Arduino.h"
#include "Wire.h"
#include <EEPROM.h>
#include <LiquidTWI.h>
#include "reflow-ovencontroller.h"
#include "open-vapors.h"
#include "reflow-thermalcouple.h"
#include "ble_adapter.h"
#include <PID_v1.h>
#include <Time.h>
#include "reflow-rtc-ds3231.h"

// LiquidCrystal over I2C.
// TODO: Verify Library used, I think it was a "fast" version of the library
LiquidTWI lcd(0);
const byte LCD_WIDTH = 20;
const byte LCD_HEIGHT = 4;

// length of the display plus a null
char messageBuffer[21];

byte buttonStates[5];  // updated in processButtons()

numberEditor numberEditorState = {0,0,0,0,0,0};

temperatureSettings currentReflowSettings[4];

// *** DISPLAY Menu Related Variables
boolean menuButtonStatus = false;
boolean enterButtonStatus = false;

menuState_t menuState;
byte menuStatus = 0;
byte menuSelectLine = 0;
byte rememberHomeMenuSelectLine = 0;

byte menuPrintLine = 0;
byte reflowEditIndex = 0;


void setup() {
  // TODO: Put serial support back in
  // original idea was to support LCD or serial interface
  #ifdef USE_SERIAL
    Serial.begin(9600);
  #endif // USE_SERIAL
  lcd.begin(LCD_WIDTH,LCD_HEIGHT);
  lcd.createChar(0, degree);
  setLCDColor(0,255,0);
  menuState = MENU_STATE_HOME;

  for (int x=0; x<5; x++)
    pinMode(buttonPins[x], INPUT_PULLUP);

  pinMode(ssrEnableButton, INPUT_PULLUP);
  pinMode(ssrPin, OUTPUT);
  ssrOFF();

  readReflowProfile();
  // initReflowSettings(); // reflashes the EEPROM, should only be used on new board/chip
  ssrOFF();

/*
  if (! rtc.begin()) {
    Serial.println(F("Couldn't find RTC"));
    Serial.flush();
    tone(buzzer_pin, error_tone, error_duration);
    while(1);
  }
*/

  // BLE Module
  pinMode(ble_state_pin, INPUT);
  Serial1.begin(9600);

  ble_available = init_ble_module();

  if (ble_available) {
    Serial.println("BLE Ready with address");
    Serial.println(ble_address);
  } else {
    Serial.println("Failed to Init BLE.");
  }

  // make the beep beep
  pinMode(buzzer_pin, OUTPUT);
  tone(buzzer_pin, normal_tone, normal_duration);
}

void serial_msg_log() {
  #ifdef USE_SERIAL
    long currentTime= (millis()-timeAtThisState) / 1000;
  //  processSyncMessage();
  //  rtc_update_stamp();
   // DateTime now = rtc.now();
    // State, Temp, Target, Time
    Serial.print(reflowState); Serial.print(F(","));
    Serial.print(currentTemperature); Serial.print(F(","));
    Serial.print(setpoint); Serial.print(F(","));
    Serial.print(currentTime); Serial.print(F(","));
    //Serial.print(now.unixtime()); Serial.print(F(",")); //rtc 
  //  Serial.print(date_string); Serial.print(F(" "));
  //  Serial.print(time_string);
    Serial.println();
  #endif
}

void heater_watchdog() {
  if (ssrState && (currentTemperature >= max_safe_temperature)) {
    ssrOFF();
    reflowState = REFLOW_STATE_THERM_FAIL;
  }

  if (ssrState && (millis() - heater_previous_millis >= runaway_timeout)) {

    int temperature_difference = abs((int)currentTemperature - (int)heater_previous_temp);
    if (temperature_difference < runaway_threshold) {
      // uh oh, bad things are happening
      // set state to alarm
      // shut off heater
      ssrOFF();
      reflowState = REFLOW_STATE_THERM_FAIL;
    } else {
      // the went up by threshold, so "reset" the timer
      heater_previous_temp = currentTemperature;
      heater_previous_millis = millis();
    }
  }
}

void loop() {
  currentMillis = millis();
  
  processSerial();
  heater_watchdog();

  if ((currentMillis - thermalcoupleMillis) >= thermalcoupleInterval) {
    updateCurrentTemp();
    thermalcoupleMillis = currentMillis;
  }

  if ((currentMillis - serialLogMillis) >= serialLogInterval) {
    serial_msg_log();
    send_ble_log();
    serialLogMillis = currentMillis;
  }

  checkSSRButton();
  processButtons();
  processMenu();
  processPID();
  determineLCDColor();
}

void checkSSRButton() {
  static int prevSSREnableButtonStatus;
  int currSSREnableButtonStatus = digitalRead(ssrEnableButton);

  if (prevSSREnableButtonStatus != currSSREnableButtonStatus) {
    delay(10);
    currSSREnableButtonStatus = digitalRead(ssrEnableButton);
    prevSSREnableButtonStatus = currSSREnableButtonStatus;

    // SSR Enable Button has been pressed
    if (currSSREnableButtonStatus == PRESSED) {
      // canceling the bake or manually enabling the SSR?
      if (reflowState == REFLOW_STATE_IDLE) {
        if (ssrState)
          ssrOFF();
        else 
          ssrON();
      } else {
        // cancel the bake
        ssrOFF();
        reflowState = REFLOW_STATE_IDLE;
        reflowStatus = REFLOW_STATUS_OFF;
      }
    }
  }
}


void processSerial() {
  #ifdef USE_SERIAL
  if (Serial.available() <1) return;

  char incomingChar = Serial.read();
  switch (incomingChar) {
    case 'I': // Enter
    case 'i':
      enterButtonStatus = true;
    break;

    case 'M':  // Menu
    case 'm':
     menuButtonStatus = true;
    break;

    case 'J':  // Move Up
    case 'j':
      if (menuSelectLine > 0) {
        menuSelectLine--;
        } else {
          flashLCDWarning();
        }
    break;

    case 'K': // move Down
    case 'k':
      if (menuSelectLine < 3) {
        menuSelectLine++;
      } else {
          flashLCDWarning();
      }
    break;

    case 'T': // epoch update 
    case 't': // rtc
      //processSyncMessage();
      Serial.println(F("Bald Dumb Dumb Deleted this..."));
    break;

    case '?': // RTC
   //   rtc_update_stamp();
   //   Serial.print(date_string); Serial.print(F(" "));
   //   Serial.println(time_string);
   // DateTime now = rtc.now();
   // Serial.println(now.timestamp()); //.toString()
      Serial.println(F("Bald Dumb Dumb Deleted this..."));
    break;
    }
  #endif USE_SERIAL
  }

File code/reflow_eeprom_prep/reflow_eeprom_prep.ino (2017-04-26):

#include "Arduino.h"
#include "Wire.h"
#include <EEPROM.h>
//#include <LiquidCrystal.h>
#include <LiquidTWI.h>

const byte lcdRGB[] = {11,10,9};

const byte LCD_WIDTH = 20;
const byte LCD_HEIGHT = 4;
char messageBuffer[21];
byte menuPrintLine=0;

LiquidTWI lcd(0);

#define EEPROM_VER 0x01

byte promValues[] = {
	1,0,
	0,0,
	150,0,
	0,0,
	90,0,
	150,0,
	200,0,
	60,0,
	120,0,
	217,0,
	254,0,
	60,0,
	150,0,
	100,0,
	50,0,
	45,0,
	200,0};

void readButton() {
	while(digitalRead(A1));
	delay(100);
	while(!digitalRead(A1));
}

void setup() {
	lcd.begin(LCD_WIDTH,LCD_HEIGHT);
	setLCDColor(0,255,127);
	pinMode(A1, INPUT_PULLUP);
	lcd.clear();
	lcd.setCursor(0,0);
	lcd.print("Press Enter to Review");
	readButton();

	lcd.clear();
	lcd.setCursor(0,0);
	lcd.print("Press Enter to begin");
	pinMode(A1, INPUT_PULLUP);
	readButton();

	lcd.clear();
	delay(100);
	setLCDColor(255,0,0);
	delay(100);

	for (int x=0; x < (sizeof(promValues) / sizeof(promValues[0])); x++) {
		EEPROM.write((x), promValues[x]);
		delay(5);
		sprintf(messageBuffer, "%d: %d - %d", x, promValues[x], EEPROM.read(x));
		//lcd.print(x); lcd.print(":"); lcd.print(promValues[x]); lcd.print(",");
		printMenuLine(messageBuffer, false);
		//delay(100);
	}


	for (int x=0; x < (sizeof(promValues) / sizeof(promValues[0])); x++) {
		EEPROM.write((100+x), promValues[x]);
		delay(5);
		sprintf(messageBuffer, "%d: %d - %d", (100+x), promValues[x], EEPROM.read(x));
		//lcd.print(x); lcd.print(":"); lcd.print(promValues[x]); lcd.print(",");
		printMenuLine(messageBuffer, false);
		//delay(100);
	}

	setLCDColor(0,255,127);
	lcd.print("Press Enter to Review");
	readButton();
	
	lcd.clear();
	lcd.setCursor(0,0);
	for (int x=0; x < (sizeof(promValues) / sizeof(promValues[0])); x++) {
		sprintf(messageBuffer, "%d: %d", x, EEPROM.read(x));
		printMenuLine(messageBuffer, true);
	}
	lcd.print("Done!");
	setLCDColor(0,255,255);
	while(1);
}

void loop() {

}

void printMenuLine(char *c, bool wait) {
  int lineWidth = LCD_WIDTH-1;
  lcd.setCursor(0,menuPrintLine);
  lcd.print(c);
  for (int x=0; x < (lineWidth-strlen(c)); x++) {
    lcd.print(" ");
  }
  menuPrintLine++;
  if (menuPrintLine > 3) {
  	menuPrintLine = 0;
  	if (wait) {
  		while(digitalRead(A1));
  		delay(100);
  		while(!digitalRead(A1));
  	}
  	else
  		delay(250);
  }
}

void setLCDColor(byte R, byte G, byte B) {
  analogWrite(lcdRGB[0], (255-R));
  analogWrite(lcdRGB[1], (255-G));
  analogWrite(lcdRGB[2], (255-B));
}

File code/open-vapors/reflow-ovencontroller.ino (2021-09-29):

// Specify PID control interface
PID reflowOvenPID(&currentTemperature, &output, &setpoint, kp, ki, kd, DIRECT);

void processPID(){
  // check for state change
  if (previous_reflowState != reflowState) {
    previous_reflowState = reflowState;  // remember new state

    tone(buzzer_pin, normal_tone, normal_duration);
  }

  // Reflow oven controller state machine
  switch (reflowState) {
    case REFLOW_STATE_THERM_FAIL:
    // print failure to screen
    printMenuLine("THERMAL FAIL");
    setLCDColor(LCD_RED);

    while(1) {
      static unsigned long prev_millis = millis();
      static bool buzz_state = true;
      ssrOFF();
      if (millis() - prev_millis >= 500) {
        if (buzz_state) {
          tone(buzzer_pin, error_tone);
          buzz_state = false;  
           #ifdef USE_SERIAL
            Serial.print(F("THERMAL FAIL"));
           #endif    
        } else {
          noTone(buzzer_pin);
          buzz_state = true;
        }

        prev_millis = millis();
      }
    }

    break;

    case REFLOW_STATE_IDLE:
      //ssrOFF();
      serialLogInterval = serial_interval_idle;
      reflowStatus = REFLOW_STATUS_OFF;
    break;

    case REFLOW_STATE_START:
      ssrOFF();
        // We want oven relatively cool before starting
        setpoint = TEMPERATURE_ROOM;
        if (true) {
       // if ((currentTemperature <= TEMPERATURE_ROOM)) {
          // Initialize PID control window starting time
          windowStartTime = millis();
          // Ramp up to minimum soaking temperature
          setpoint = currentReflowSettings[soak].tempMin;
          // Tell the PID to range between 0 and the full window size
          reflowOvenPID.SetOutputLimits(0, windowSize);
          reflowOvenPID.SetSampleTime(PID_SAMPLE_TIME);
          // Turn the PID on
          reflowOvenPID.SetMode(AUTOMATIC);
          // Proceed to preheat stage
          timeAtThisState = millis();
          reflowState = REFLOW_STATE_PREHEAT;
          serialLogInterval = serial_interval_active;
        }
    break;

    case REFLOW_STATE_PREHEAT:
      reflowStatus = REFLOW_STATUS_ON;
      // If minimum soak temperature is achieve       
      if (currentTemperature >= currentReflowSettings[soak].tempMin) {
        // If we ramped too quickly, calm the ramp down
        reflowOvenPID.SetTunings(PID_KP_SOAK, PID_KI_SOAK, PID_KD_SOAK);
        // Time for soaking stage?
        if ((millis() - timeAtThisState) > (currentReflowSettings[preheat].timeMin)) {
          timeAtThisState = millis();
          reflowState = REFLOW_STATE_SOAK;   
        }
      }
    break;

    case REFLOW_STATE_SOAK:     
      // Set less agressive PID parameters for soaking ramp
      reflowOvenPID.SetTunings(PID_KP_SOAK, PID_KI_SOAK, PID_KD_SOAK);
      // Set midpoint halfway, we're going to overshoot a little
      // setpoint = ((currentReflowSettings[soak].tempMax - currentReflowSettings[soak].tempMin) / 2) + currentReflowSettings[soak].tempMin;
      setpoint = ((currentReflowSettings[soak].tempMax - currentReflowSettings[soak].tempMin)) + currentReflowSettings[soak].tempMin;
      // Make sure we sit at soak for long enough. Really helps with the reflow-peak
      if (currentTemperature > currentReflowSettings[soak].tempMin) {
        if ((millis() - timeAtThisState) > (currentReflowSettings[soak].timeMin * 1000UL)) {  
          // Proceed to reflowing state
          timeAtThisState = millis();
          reflowState = REFLOW_STATE_REFLOW; 
        }
      }
    break; 

    case REFLOW_STATE_REFLOW:
      // Set agressive PID parameters for reflow ramp
      reflowOvenPID.SetTunings(PID_KP_REFLOW, PID_KI_REFLOW, PID_KD_REFLOW);
      // Ramp to max temp.
      setpoint = currentReflowSettings[reflow].tempMax; 

      // compensating for overshoot
   /*   if (setpoint - currentTemperature <= 10.0) {
        reflowOvenPID.SetTunings(PID_KP_PREHEAT, PID_KI_PREHEAT, PID_KD_PREHEAT);
      }*/
        
      // got our min temp, will still hit the peak by interita. 
      if (currentTemperature > currentReflowSettings[reflow].tempMax) {
        // Proceed to dwell state
        timeAtThisState = millis();
        reflowState = REFLOW_STATE_DWELL; 
      }
    break;   

    case REFLOW_STATE_DWELL:
      // TODO: change timeAtThisState to include the time from when peak was hit
      // which would make settings for Reflow Max be: Reflow + Dwell
      // instead of the hardcoded 15 and 30 seconds here.
      setpoint = ((currentReflowSettings[reflow].tempMax - currentReflowSettings[reflow].tempMin) / 2) + currentReflowSettings[reflow].tempMin; 

      // just maintaining temp here, so conservative values
      reflowOvenPID.SetTunings(PID_KP_DWELL, PID_KI_DWELL, PID_KD_DWELL);
      if ((currentTemperature >= currentReflowSettings[reflow].tempMin) && (millis() - timeAtThisState >= 15000UL)) {
        reflowState = REFLOW_STATE_COOL;
        setpoint = currentReflowSettings[cool].tempMin;          
        timeAtThisState = millis();        
      }

      if (millis() - timeAtThisState >= 30000UL) {
        // spent too long here
        // TODO: Throw an Error
        reflowState = REFLOW_STATE_COOL;
        // TODO, cooling isn't working right.
        setpoint = currentReflowSettings[cool].tempMin;          
        timeAtThisState = millis();     
      }
    break;

    case REFLOW_STATE_COOL:
      // should keep heater available to achieve min cool down rate
      // but not usually an issue
      reflowStatus = REFLOW_STATUS_OFF;   
      ssrOFF();   
      // If minimum cool temperature is achieve       
      if (currentTemperature <= currentReflowSettings[cool].tempMin)
      {
        // Retrieve current time for buzzer usage
        // TODO: Renable the buzzer code
        // also, I don't like how original code used millis()
        //buzzerPeriod = millis() + 1000;

        //digitalWrite(buzzer, HIGH);
        // Turn off reflow process
        reflowStatus = REFLOW_STATUS_OFF;                
        
        // Proceed to reflow Completion state
        timeAtThisState = millis();
        reflowState = REFLOW_STATE_COMPLETE; 
      }         
      break;    

    case REFLOW_STATE_COMPLETE:
      setpoint = 0;
     // if (millis() > buzzerPeriod)
     // {
        // Turn off buzzer
        //digitalWrite(buzzer, LOW);
        // Reflow process ended
        timeAtThisState = millis();
        reflowState = REFLOW_STATE_IDLE; 
        ssrOFF();
     // }
      break;
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

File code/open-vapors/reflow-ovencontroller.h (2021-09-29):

// ***** REFLOW TYPE DEFINITIONS *****
typedef enum REFLOW_STATE{
  REFLOW_STATE_IDLE,
  REFLOW_STATE_START,
  REFLOW_STATE_PREHEAT,
  REFLOW_STATE_SOAK,
  REFLOW_STATE_REFLOW,
  REFLOW_STATE_DWELL,
  REFLOW_STATE_COOL,
  REFLOW_STATE_COMPLETE,
  REFLOW_STATE_ERROR,
  REFLOW_STATE_THERM_FAIL
} 
reflowState_t;

typedef enum REFLOW_STATUS{
  REFLOW_STATUS_OFF,
  REFLOW_STATUS_ON
} 
reflowStatus_t;

typedef enum DEBOUNCE_STATE{
  DEBOUNCE_STATE_IDLE,
  DEBOUNCE_STATE_CHECK,
  DEBOUNCE_STATE_RELEASE
} 
debounceState_t;

// ***** CONSTANTS *****

#define TEMPERATURE_ROOM 50

unsigned long runaway_timeout = 30000;
unsigned long heater_previous_millis = 0;
float heater_previous_temp = 0.0;
int runaway_threshold = 2;
float max_safe_temperature = 245.0;

// These constants are here from original code
// most have been converted to variables and
// are stored in EEPROM
// TODO: Clean up constants
#define TEMPERATURE_SOAK_MIN 65
#define TEMPERATURE_SOAK_MAX 75
#define TEMPERATURE_REFLOW_MAX 100
#define TEMPERATURE_COOL_MIN 50
#define SENSOR_SAMPLING_TIME 250
#define SOAK_TEMPERATURE_STEP 5
#define SOAK_MICRO_PERIOD 9000
#define DEBOUNCE_PERIOD_MIN 50
#define THERMOCOUPLE_DISCONNECTED 10000

// ***** PID PARAMETERS *****
#define PID_SAMPLE_TIME 1000

// ***** PRE-HEAT STAGE *****
// TODO: Convert these to variables and store in EEPROM
// Original code values were way to aggressive
#define PID_KP_PREHEAT 25
#define PID_KI_PREHEAT 0.08
#define PID_KD_PREHEAT 10
// ***** SOAKING STAGE *****
#define PID_KP_SOAK 50
#define PID_KI_SOAK 0.05
#define PID_KD_SOAK 250
// ***** REFLOW STAGE *****
#define PID_KP_REFLOW 250
#define PID_KI_REFLOW 0.05
#define PID_KD_REFLOW 375
// ***** DWELL STAGE *****
#define PID_KP_DWELL 25
#define PID_KI_DWELL 0.025
#define PID_KD_DWELL 20

// ***** PID CONTROL VARIABLES *****
// PID Library expects doubles, even though
// arduino doesn't support them
double setpoint;
double input;
double output;
double kp = PID_KP_PREHEAT;
double ki = PID_KI_PREHEAT;
double kd = PID_KD_PREHEAT;
int windowSize = 2000;
unsigned long windowStartTime;
unsigned long nextCheck;
unsigned long nextRead;
unsigned long timerSoak;
//unsigned long buzzerPeriod;
unsigned long timeAtThisState=0;

// Reflow oven controller state machine state variable
reflowState_t reflowState;
reflowState_t previous_reflowState;

// Reflow oven controller status
reflowStatus_t reflowStatus;

// TODO: Figure out what degree symbol LCD is using
// ***** DEGREE SYMBOL FOR LCD *****
/*unsigned char degree[8]  = {
  140,146,146,140,128,128,128,128};*/

// calculated value from: https://omerk.github.io/lcdchargen/
// neither of these are used right now.
byte degree[8] = {
  0b00111,
  0b00101,
  0b00111,
  0b00000,
  0b00000,
  0b00000,
  0b00000,
  0b00000
};

// Track SSR State
bool ssrState = false;

// ***** PIN ASSIGNMENT *****
// TODO: Move other Pin Assignments here (buzzer)
int ssrPin = 5;
int ssrEnableButton = 6;

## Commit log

2021-09-15 overdue commit, prepping for v2 update
    [Bottom Panel.ipt, Box Back.ipt, Box Bottom.ipt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]
2021-09-15 archiving original control board created in EAGLE
    [Keypad.brd, Keypad.sch, Reflow Control Board Rev 2.brd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]
2021-09-15 rev board converted from EAGLE to KiCad
    [Reflow Control Board Rev 2.kicad_pcb, Reflow Control Board Rev 2.sch]
2021-09-25 initial BLE support reporting current temperature
2021-09-29 change the soak state to accomodate proper soaking. also changed thermal timeout to be absolute value to account for if the temperature drops.
2021-09-29 fixed soak stage bug, fix manual SSR control, added max temperature check
    [menu-Manual.ino, open-vapors.ino, reflow-ovencontroller.h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]
2022-02-08 Added PDF of the schematic.
    [Reflow Control Board Rev 2.sch]

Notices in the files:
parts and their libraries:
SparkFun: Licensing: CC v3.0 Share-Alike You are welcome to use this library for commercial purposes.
